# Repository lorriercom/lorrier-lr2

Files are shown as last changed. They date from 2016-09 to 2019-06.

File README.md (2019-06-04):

Lorrier LR2 repository
======================

-   RouterOS & ARM config files

-   PCB gerber files

-   Web administration files

-   Settings instructions

LR2 Gateway (comes preconfigured)
---------------------------------

### Quick Settings

-   Follow instructions in
    [LR2_Quick_Settings.md](https://github.com/lorriercom/lorrier-lr2/blob/master/LR2_Quick_Settings.md)
    file

-   That instructions are enough for LR2 complete easy settings

### LR2 Gateway consist of this 3 parts:

-   Mikrotik Routerboard RB951Ui-2nD (https://routerboard.com/RB951Ui-2nD)

-   SeedStudio BeagleBone Green (https://beagleboard.org/green)

-   IMST iC880A
    (http://www.wireless-solutions.de/products/long-range-radio/ic880a.html)

### Routeroard

-   Routerboard configuration in
    [/routeros/routerboard_configuration.md](https://github.com/lorriercom/lorrier-lr2/blob/master/routeros/routerboard_configuration.md)
    file.

-   Routeros backup files: /routeros/lorrier.rsc and /routeros/lorrier.backup

### BeagleBone Green (BBG)

-   BBG configuration in [/bbg
    configuration/bbg_configuration.md](https://github.com/lorriercom/lorrier-lr2/tree/master/bbg%20configuration/bbg_configuration.md)
    file.

-   You can update your BBG by latest image. Image flashing instructions are in
    [/bbg
    configuration/bbg_flashing.md](https://github.com/lorriercom/lorrier-lr2/tree/master/bbg%20configuration/bbg_flashing.md)
    file. Be sure you have also the Routerboard updated by latest backup file.

-   LR2 Images download in [/bbg
    configuration/bbg_images.md](https://github.com/lorriercom/lorrier-lr2/tree/master/bbg%20configuration/bbg_images.md)
    file.

LR2 Gateway troubleshooting
---------------------------

### BeagleBone freezing (occurred in isolated cases)

**Issue:** BBG freezes from time to time, ie. it stops responding after some
time in service. BBG system apparently freezes and GW stops receiving and
sending payload. The BBG cannot be communicated, web administration is not
available. The other GW systems (Routerboard) are in normal use.

**Cause of the problem:** LR2 IoT concentrator consists of a BBG + IC880a
tandem. This whole system is powered by USB-UART converter, which is connected
to USB port of Mikrotik Routerboard. Under certain circumstances, especially
when transmission from the IC880a is initiated, the peak consumption of BBG +
IC880a tandem is greater than the maximum consumption threshold of some chips
used for the USB-UART converter in LR2 (eg FTDI FT232RL). In this case, some
USB-UART chips can initiate a PWREN \# sequence to check the power consumption
of the connected devices. Some external logic has the ability to power itself
down into a low current state by monitoring the PWREN\# signal. For external
logic that cannot power itself down in this way, those chips provides a simple
but effective method of turning off power during the USB suspend mode. When this
happens in LR2, the BBG gets a shutdown command and turns off. Alternatively,
the power supply for BBG + IC880a tandem from the USB-UART converter is turned
off.

**Solution:**

There are two possibilities to solve this problem:

a) replace an existing USB-UART converter that feeds BBG + IC880a with another
type that has a maximum power threshold set to a higher level. Replacing the
USB-UART converter is very simple and inexpensive.

b) use a simple USB Pin Header cable instead of a USB-UART converter. Since USB
is only used for power (other features using TX and RX connectors have not yet
been used in LR2), it is only possible to use power connectors (VCC + 5V and
GND) directly from USB.

Note: For both cases, the LR2 top cover must be removed of course. No effort is
needed to eject the USB-UART converter. On the RouterBoard side, just pull out
the USB connector. On the BBG + IC880a side, the connectors are inserted into
the pins on the Lorrier Bl PCB (Lora Adapter) and secured with a drop of glue
from the melt gun. It needs to be loosened and the individual connectors pinned
out gently. When replacing with a new USB-UART converter or USB pin Header cable
it is necessary to keep the correct polarity!

### Lorrier.com not responding

The Lorrier company changed its ownership structure and disappeared as a
manufacturer of IoT devices in 2019. However, this does not change the
functionality and support of existing LR2 gateways, as the entire system is
released as open-source and fully customizable by the user. All support
documents and materials are posted on Lorrier github.

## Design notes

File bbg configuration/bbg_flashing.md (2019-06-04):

BBG Image Flashing Procedure
============================

There are several possibilities how to flash a new image to the BeagleBone
Green. Here we describe two of them:

### 1) microSD automatic extracting contents (not recommended for newest LR2 versions)

-   Get a 4GB or larger microSD card that is FAT formatted.

-   Make sure that the partition on the microSD card is marked as active.

    **NOTE**: To mark a partition as active in Windows 7: Open command prompt
    and enter the following commands: diskpart -\> list disk -\> select disk x
    (where x is the microSD card) -\> list partition -\> select partition 1
    (assuming the microSD card has 1 partition) -\> active.

-   Download
    [Flash\_From\_SD\_to\_eMMC.zip](https://drive.google.com/open?id=0B2d6XCsqk9PSREFxVFRpUG5MNTA)
    and extract the contents onto your microSD card.

-   Download desired image and place it onto your microSD card. The list of the
    images is in [/bbg
    configuration/bbg\_images.md](https://github.com/lorriercom/lorrier-lr2/blob/master/bbg%20configuration/bbg_images.md)
    file. Make sure there is a valid Lorrier\_LR2\_BBG\_vXXXXX.img.gz file on
    the microSD card.

-   Edit autorun.sh on your microSD card with your favorite text editor to
    replace XXXXX with your actual image number.

-   Remove the white cover of the LR2 by unscrewing four Allen screws. Eject
    microSD card from your computer, insert it into powered-off BeagleBone Green
    and apply power to your LR2.

    

-   You'll notice USR0 (the LED closest to the S1 button in the corner) will
    (after few seconds) start to blink steadily, rather than the double-pulse
    "heartbeat" pattern that is typical when your BeagleBone Green is running
    the typical Linux kernel configuration.

-   It'll run for a bit under 10 minutes and then USR0 will stay ON steady.
    That's your cue to remove power and remove the microSD card.

-   Apply power to the LR2 again, let it boot completely and check new image is
    working correctly.

*This procedure is based on “BeagleBone Black Extracting eMMC contents”:
http://elinux.org/BeagleBone\_Black\_Extracting\_eMMC\_contents*

### 2) BeagleBoard eMMC flasher (recommended)

-   Download desired LR2 image. The list of the images is in /bbg
    configuration/bbg\_images.md file
    (https://github.com/lorriercom/lorrier-lr2/blob/master/bbg
    configuration/bbg\_images.md).

-   Decompress Lorrier\_LR2\_BBG\_vXXXXX.img.gz file using
    [7-zip](http://www.7-zip.org/download.html).

-   Download and install [Image Writer for
    Windows](https://sourceforge.net/projects/win32diskimager/files/latest/download).
    Be sure to download the binary distribution.

-   Connect 4GB or larger microSD card into your computer.

-   Use Image Writer to write the decompressed image to your SD card.

    

-   Eject microSD card from your computer, insert it into your powered-off
    BeagleBone Green and apply power.

-   Connect to your BBG through SSH (for example using the Putty:
    http://www.putty.org/). The BBG SSH is available on port 2222. Default
    login: user= root , password= lorrier

-   In /boot/uEnv.txt:

~~~~~~~~~~~~~~~~~~~~~~~~~~~~~~~~~~~~~~~~~~~~~~~~~~~~~~~~~~~~~~~~~~~~~~~~~~~~~~~~
    ##enable BBB: eMMC Flasher:
    #cmdline=init=/opt/scripts/tools/eMMC/init-eMMC-flasher-v3.sh
~~~~~~~~~~~~~~~~~~~~~~~~~~~~~~~~~~~~~~~~~~~~~~~~~~~~~~~~~~~~~~~~~~~~~~~~~~~~~~~~

Change to:

~~~~~~~~~~~~~~~~~~~~~~~~~~~~~~~~~~~~~~~~~~~~~~~~~~~~~~~~~~~~~~~~~~~~~~~~~~~~~~~~
    ##enable BBB: eMMC Flasher:
    cmdline=init=/opt/scripts/tools/eMMC/init-eMMC-flasher-v3.sh
~~~~~~~~~~~~~~~~~~~~~~~~~~~~~~~~~~~~~~~~~~~~~~~~~~~~~~~~~~~~~~~~~~~~~~~~~~~~~~~~

-   Reboot the system, it'll flash the eMMC on the next bootup. When the
    flashing is complete, all 4 USRx LEDs will be steady on or off. *This can
    take up to 45 minutes.* Power-down your board, remove the SD card and apply
    power again to be complete.

*This procedure is based on “BeagleBoard getting started”:
https://beagleboard.org/getting-started\#update*

Troubleshooting:
----------------

-   Sometimes, after the new image is flashed, you may need to reboot LR2
    several times.

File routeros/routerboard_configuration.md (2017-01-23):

Routerboard configuration
=========================

For Routerboard setting use **Winbox tool** (Windows users download
[here](http://www.mikrotik.com/download) on the bottom of the page. Mac OS users
download [here](http://mikrotikdownload.s3.amazonaws.com/WinBox-macOS.zip).
Detailed information about Winbox tool are
[here](http://wiki.mikrotik.com/wiki/Manual:Winbox).)

**! Please note,** default reset always disable CDP (cisco discovery protocol)
on PoE-in interface (ether1). You can enable CDP in Winbox/SSH.

Default configuration
---------------------

-   winbox standard port 8291, ssh standard port 22, other services disabled

-   login / password: admin / lorrier

-   cisco discovery protocol on all interfaces

-   ether1\_wan: 192.168.1.2/24, gw 192.168.1.2, DHCP client OFF

-   ether5\_local: 10.10.10.1 + DHCP server (ranges=10.10.10.2, 1 IP only)

-   Default gateway: 192.168.1.1

-   src&dst nat for arm IP address (SSH 2222 \> 22) set and disabled

-   src&dst nat for arm IP address (HTTPS 443 \> 443) set and disabled

-   src&dst nat for arm IP address (HTTP 80 \> 80) set and disabled

-   DNS services, 4 x public DNS (OpenDNS and Google public DNS)

-   NTP services, 2 x ntp.org (US, EU)

-   Wireless packages disabled (System -\> Packages: wireless-cm2 = disable,
    wireless-fp = disable)

### Restore default configuration

-   Download the
    [/routeros/lorrier.backup](https://github.com/lorriercom/lorrier-lr2/blob/master/routeros/)
    file

-   Login to your LR2 with Winbox and open “Files” window

-   Drag & drop the lorrier.backup file into the “Files” window

-   Click on this file to highlight it and then click on “Restore”

Routerboard settings instructions
---------------------------------

### Routerboard password change

-   System -\> Password

-   Default password: admin

### GW static IP address change

-   IP -\> Addresses

-   Change IP address on ether1\_wan (from default 192.168.1.2/24). IP address
    with mask format record have to be retained

-   IP -\> Routes -\> Dst. Address 0.0.0.0/0 : Set (network!) gateway IP address

### Dynamic IP Address enable = DHCP Client ON

-   From Winbox connect using MAC adress

-   IP -\> Addresses

-   Disable IP address on ether1\_wan (click on red cross icon)

-   IP -\> DHCP Client -\> Add; Interface = ether1\_wan; Use Peer DNS = yes; Use
    Peer NTP = yes; DHCP Options = host name + clientid; Add Default Route = yes

### IP access Restrictions (Recomended)

-   IP -\> Firewall -\> Adress list -\> Add; Name = allow; Address = Your
    allowed IP address(es)

-   IP -\> Firewall -\> NAT; 1. dst-nat (dst. port 2222) =\> **General:** Chain
    = dstnat; Protocol = 6 (tcp); Dst. Port = 2222. **Advanced:** Src. Address
    List = allow. **Action:** Action = dst-nat; To Address = 10.10.10.2; To
    Ports = 22

-   IP -\> Firewall -\> NAT; 2. dst-nat (dst. port 443) =\> **General:** Chain =
    dstnat; Protocol = 6 (tcp); Dst. Port = 443. **Advanced:** Src. Address List
    = allow. **Action:** Action = dst-nat; To Address = 10.10.10.2; To Ports =
    443

-   IP -\> Firewall -\> NAT; 3. dst-nat (dst. port 80) =\> **General:** Chain =
    dstnat; Protocol = 6 (tcp); Dst. Port = 80. **Advanced:** Src. Address List
    = allow. **Action:** Action = dst-nat; To Address = 10.10.10.2; To Ports =
    80

-   IP -\> Firewall -\> Filter Rules -\> Add; **General:** Chain = input;
    Protocol = 6 (tcp); Dst. Port = 22,8291,80,443. **Advanced:** Src. Address
    List = !(Not) allow. **Action:** Action = drop; To Address = 10.10.10.2; To
    Ports = 22

-   All Records (Rules, NATs, Address lists) must be enabled = not gray

### DNS Servers change

-   IP -\> DNS -\> Servers

-   Fill out the IP adress(es) of your desired DNS server(s)

-   Apply (OK)

Troubleshooting
---------------

-   If your network has different IP range than your LR2, you might need to
    connect it by MAC address:

    1.  Find your LR2 (identity: Lorrier) in the “Neighbors” window.

    2.  Click on the appropriate line in the MAC address column. You will see
        the “Connect to:” box on the top of the window change to the LR2 MAC
        address.

    3.  Fill out the right login and the password (in default: admin / lorrier)

    4.  Click connect.

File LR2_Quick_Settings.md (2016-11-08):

LR2 Quick Settings
==================

Preconfigured LR2 since version 2.1.0 is running on Debian (versions may vary)
which contains web administration environment.

1.  Connect the antenna to your LR2. Do not use this unit without antenna or
    appropriate attenuator connected.

2.  Connect your LR2 using enclosed POE adapter to your network. Default network
    setting is Static IP: 192.168.1.2. Booting of the LR2 takes about 60
    seconds.

3.  Set your Routerboard password. To change Routerboard password or to change
    network setting, follow the instructions in
    [/routeros/routerboard\_configuration.md](https://github.com/lorriercom/lorrier-lr2/blob/master/routeros/routerboard_configuration.md)
    file.

4.  Set your BBG password: Use SSH connection on port 2222 (default setting
    192.168.1.2:2222). Default login: username: *root* / password: *lorrier*. In
    the command line type *passwd root* and *passwd debian* to change your
    password.

5.  Type *192.168.1.2* (or your new IP setting) in your web browser and
    authorize the safety certificate to open web administration environment.

6.  Enter your login. The default login: username = *admin* / password =
    *lorrier*

7.  Choose your Packet Forwarder or network server service in the
    Settings-\>Forwarder window. The MAC address information (primarily for
    Loriot.io service) can be found in Dashboard-\>Device Info. After Packet
    Forwarder change, you may need to reboot your Gateway in Dashboard window.

8.  If needed, you can change your Gateway ID in the Settings/Gateway ID window.

9.  Set your web administration password in the Preferences window.

**NOTE:**

-   Be sure, your computer from which you are trying to reach web administration
    is in the same network as the LR2 (in default settings: 192.168.1.X). If
    your network has another range, you need to
    [change](https://github.com/lorriercom/lorrier-lr2/blob/master/routeros/routerboard_configuration.md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)
    LR IP address to be correct in your IP network range.

-   Be sure LR2 is able to connect to the internet. The web administration
    environment gets the network server services from the
    /github.com/lorriercom/lorrier-lr2/servers.json file. When the internet
    connection is missing, the page refresh would last for quite long time and
    there is only TTN Basic packet forwarder, TTN Poly packet forwarder and
    Loriot.io choice active. Obviously, in such a case LR2 can not send the
    payloads to network server.

-   For maximizing network security we strictly recommend you to set [IP address
    restrictions](https://github.com/lorriercom/lorrier-lr2/blob/master/routeros/routerboard_configuration.md)
    on your routerboard to avoid possible cyber attacks.

-   Since version 2.1.1, BBG access is protected by fail2ban (login brute force
    attack protection). You have 3 login attempts, then you have to wait for 15
    minutes to next try.

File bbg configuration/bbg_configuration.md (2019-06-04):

Beaglebone (comes preconfigured)
================================

The following procedure describes manual LR2 configuration for 1.0.1 version
(without newer LR2 firmware features).This is useful for understanding the basic
system settings and for debugging.

Default login: username: *root* / password: *lorrier*

### Download zipped binaries and autostart files

-   Download
    [lr2_debian7-v1.0.1.](https://webshare.cz/file/2hr40f2B23/lorrier-lr2-bbg-v1-0-1-img-gz)

-   Unzip as /opt/lorrier

-   Make symlink for autostart from /opt/lorrier/lorrier.service to
    /lib/systemd/system/lorrier.service

-   Make second symlink for autostart from /opt/lorrier/lorrier.service to
    /lib/systemd/system/multi-user.target.wants/lorrier.service

-   Find the kernel version (uname -a)

-   For kernel 3x enable SPI bus, in /boot/uEnv.txt add
    cape_enable=capemgr.enable_partno=BB-SPIDEV0

-   For kernel 4x enable SPI bus, in /boot/uEnv.txt add
    cape_enable=bone_capemgr.enable_partno=BB-SPIDEV0

-   Restart (shutdown -r now)

### Quick help

-   Set IP/DNS address of network server in /opt/lorrier/global_conf.json

-   Optionaly set your own Gateway ID in /opt/lorrier/local_conf.json and
    disable auto-generated Gateway ID, in /opt/lorrier/set-gateway-id.sh set
    IOT_SK_GWID_UPDATE=false

-   Service management: service lorrier status\|start\|stop\|restart

-   Test of proper function of LoRa RF concentrator: /opt/lorrier/test.sh

-   Version of the GW image: /opt/lorrier/gwVersion.txt

### Compile your own (basic) packet fowarder from https://github.com/Lora-net

-   get the HAL driver from https://github.com/Lora-net/lora_gateway and do
    "make"

-   get the packet forwarder from https://github.com/Lora-net/packet_forwarder
    and do "make"

### Compile your own (poly) packet fowarder from https://github.com/TheThingsNetwork

-   get the HAL driver form https://github.com/TheThingsNetwork/lora_gateway

-   channge directives "CFG_SPI= native" and "PLATFORM= lorank" in
    /libloragw/library.cfg and do "make"

-   get the packet forwarder from
    https://github.com/TheThingsNetwork/packet_forwarder and do "make"

### Get your own Loriot.io binary file

-   Follow instructions from Loriot.io Control Panel for Lorrier LR2 compatible
    device.

### Installing fail2ban

-   Install aptitude: apt-get install aptitude

-   Follow fail2ban [installing
    instructions](https://www.upcloud.com/support/installing-fail2ban-on-debian-8-0/)

### Installing LoRa Gateway Bridge (brocaar)

-   Follow LoRa Gateway Bridge [installing
    instructions](https://docs.loraserver.io/lora-gateway-bridge/getting-started/#install-lora-gateway-brige)

### Installing LoRa Server (brocaar)

-   Follow LoRa Server [installing
    instructions](https://docs.loraserver.io/loraserver/getting-started/)

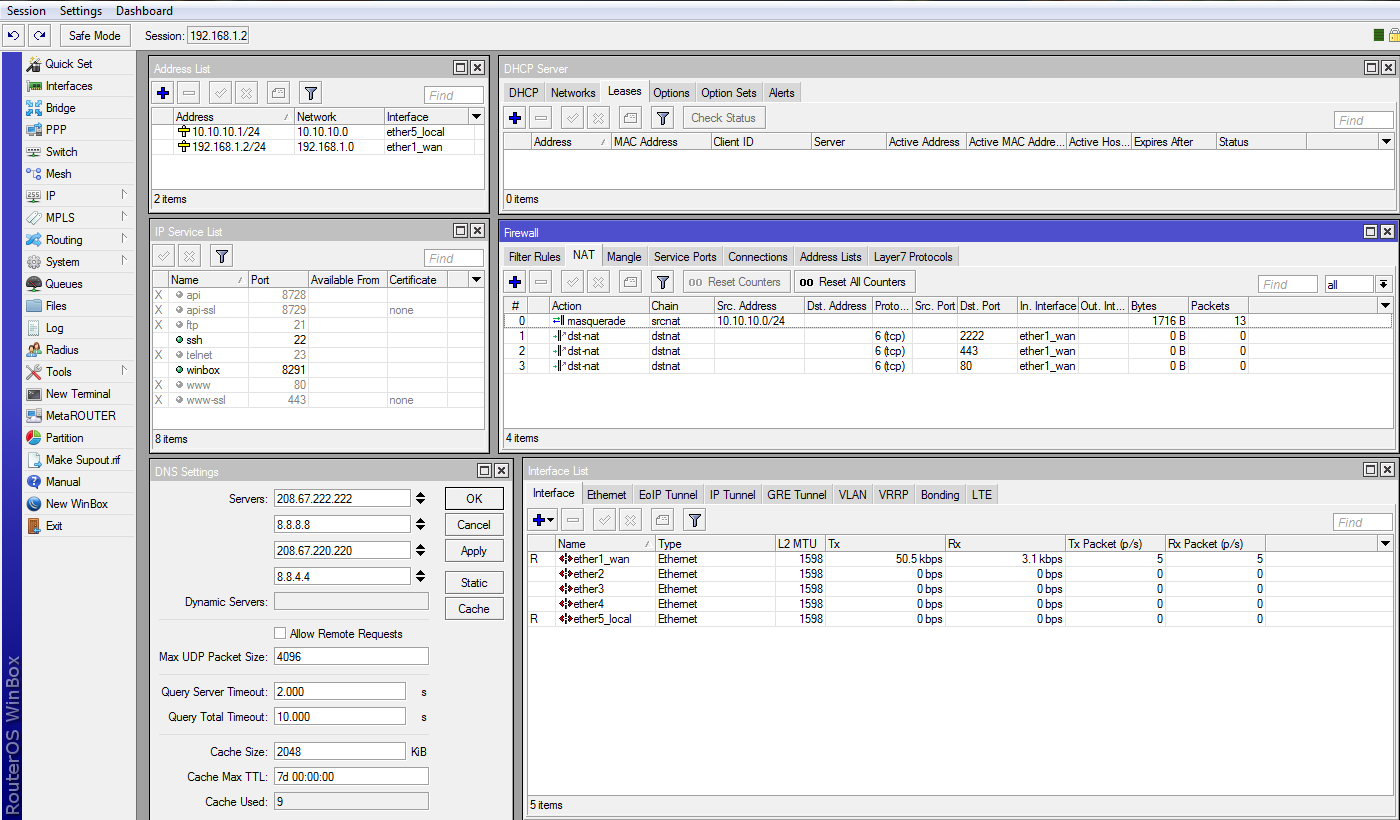
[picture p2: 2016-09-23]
routeros/routeros.png

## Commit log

2016-06-02 PCB gerber files added
    [bot.gbr, mill.gbr, plb.gbr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]
2016-08-15 replaced with commas
    [servers.csv]
2016-08-15 minor changes
    [servers.csv]
